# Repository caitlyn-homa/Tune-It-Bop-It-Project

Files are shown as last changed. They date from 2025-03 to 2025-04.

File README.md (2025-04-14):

# Tune-It-Bop-It-Project

## ATMega328p I/O List
| Description | Pin | Label |
| --- | --- | --- |
| Tuner | A0 | TNR |
| Volume | A3 | VOL |
| OLED/Accelerometer  | A4 |  SDA  |
| | A5  |  SCL |
| Speaker (SPK) | 0 | RX |
| | 1 | TX |
| Pull | 2 | PUL | 
| Reset | 3 | RST |
| Motor Reset | 4 | MLS |
| Stepper (MTR) | 5 | st_a |
|  | 6 | st_b |
|  | 7 | st_c |
|  | 8 | st_d |
| Reset LED | 9 | RLD |

## File Directory

### Final_Code
This folder contains the final code uploaded to the microcontroller.
This consists of the main game code as well as the modified class for the mp3 player.

### 3D Print Files
This folder contains every file used for 3D printing, this includes the enclosure as well as the internal mechanical mechanisms.

### prorotype_functions
This contains functions that were created later in the software development and were written in a separate file before integration.

### test_scripts
These scripts were used in the interfacing stage of development and were referenced throughout the process of creating the final code.

### PCB_Files
These files in the design and manufacturing of the PCB, this includes the schematic, the pcb design file, and the exported manufacturing files.

### laser_cut
These files were used to laser cut the score dial and the mesh on the front of the device.

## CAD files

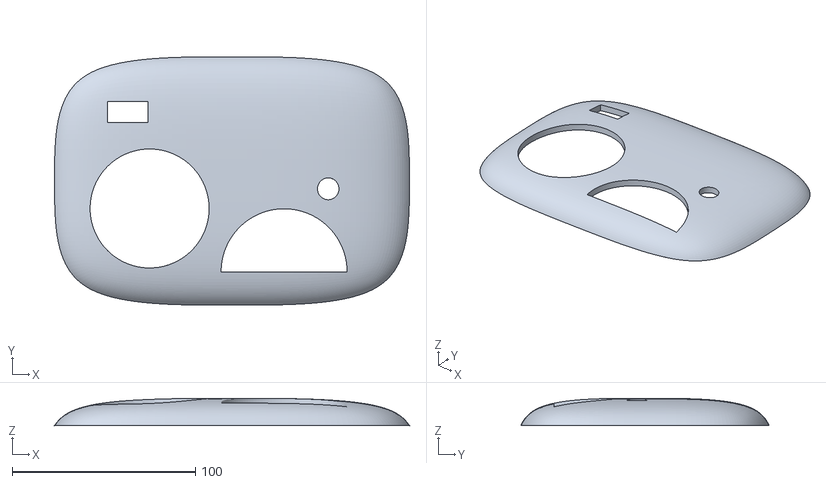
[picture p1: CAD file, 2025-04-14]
3D Print Files/bubbly bop it lid.stl
193.9 x 135.7 x 15.0

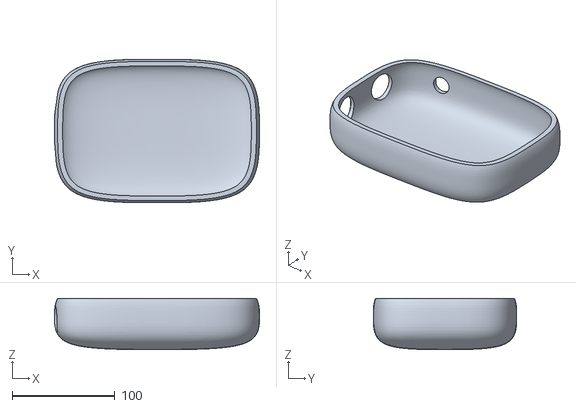
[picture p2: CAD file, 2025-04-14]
3D Print Files/bubbly bop it bottom.stl
200.0 x 140.0 x 50.0

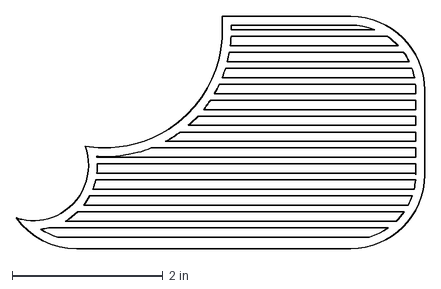
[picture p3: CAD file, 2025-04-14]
laser_cut/grid v2 v1.dxf
5.42 x 3.09 in

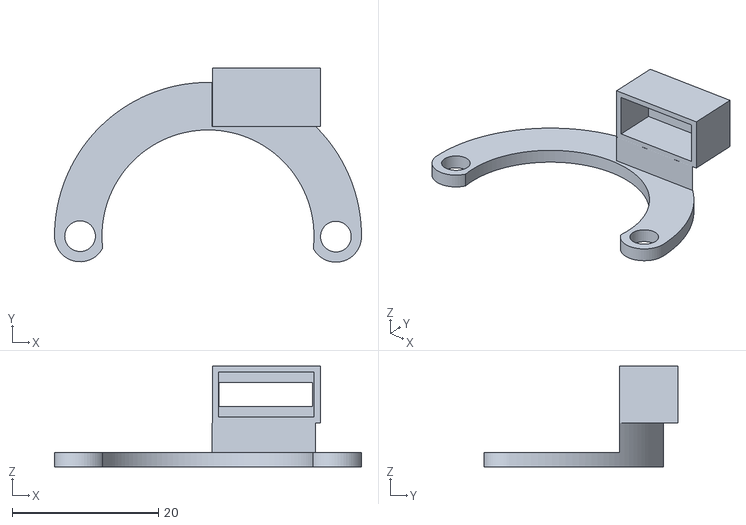
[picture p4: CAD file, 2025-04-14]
3D Print Files/LimitSwitch v1.stl
42.0 x 26.6 x 13.8

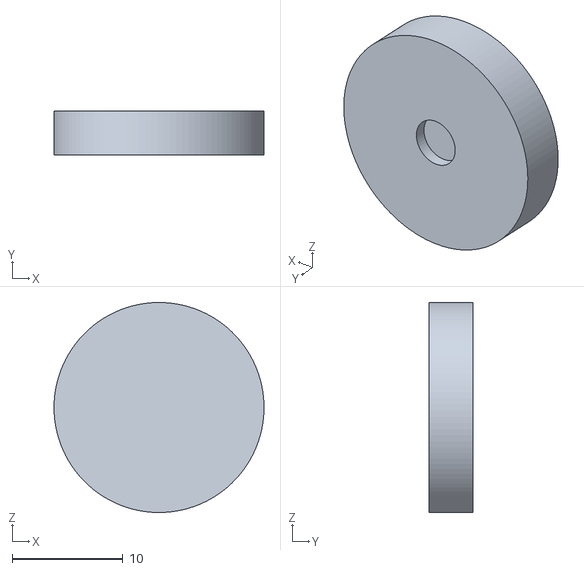
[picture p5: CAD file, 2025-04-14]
3D Print Files/antenna_base.stl
18.9 x 4.00 x 18.9

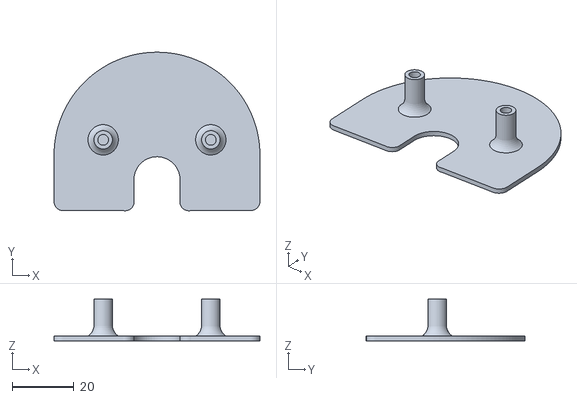
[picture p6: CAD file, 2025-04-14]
3D Print Files/ScorePlate v4.stl
67.0 x 51.6 x 13.5

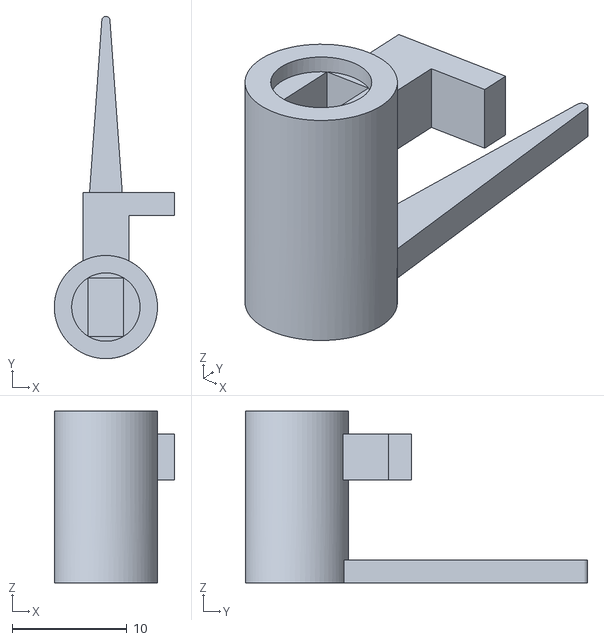
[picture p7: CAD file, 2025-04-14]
3D Print Files/Needle v1.stl
10.5 x 29.9 x 15.0

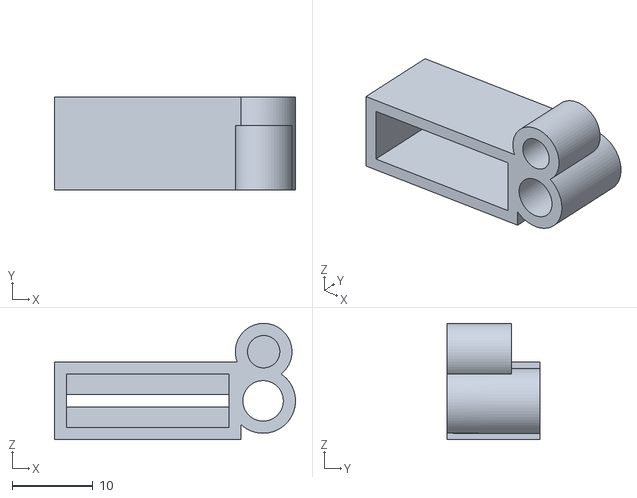
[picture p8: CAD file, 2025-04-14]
3D Print Files/antenna_switch.stl
29.8 x 11.5 x 14.4

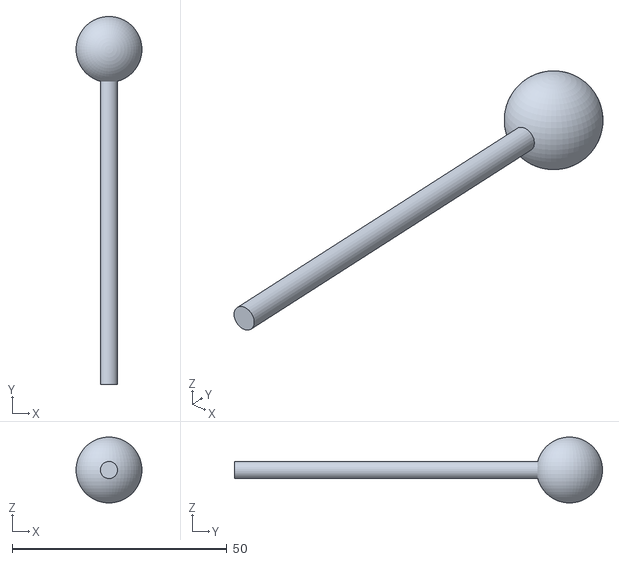
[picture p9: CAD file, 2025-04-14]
3D Print Files/antenna_rod.stl
15.3 x 85.7 x 15.3

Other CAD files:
laser_cut/score dial important v2.dxf

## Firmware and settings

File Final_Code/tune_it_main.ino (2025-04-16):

#include <DFMiniMp3.h>
#include <Adafruit_SSD1306.h>
#include <Adafruit_GFX.h>
#include <SPI.h>
#include <Wire.h>
#include "SparkFunLIS3DH.h" 
#include "Mp3Manager.hpp"

//OLED Variables & Object
#define SCREEN_WIDTH 128
#define SCREEN_HEIGHT 64
#define OLED_ADDR 0x3C
Adafruit_SSD1306 display(SCREEN_WIDTH, SCREEN_HEIGHT, &Wire, -1);

//Accelerometer Object
LIS3DH SensorOne(I2C_MODE, 0x19);
//SD Card Object
Mp3Manager mp3;

//In-Game Variables 
byte score = 0;
byte iteration = 0;
bool isComplete = false;
volatile bool restartPressed = false;
int numRounds = 99;
float time_to_complete = 4.0;
//Used to calculate time interval decrease - following exponential decay
float time_constant = -numRounds/log(0.7/4); 

int volume = analogRead(A3)/20.5;

//Used to debug when having memory issues 
extern int __heap_start, *__brkval;
int freeMemory() {
  int v;
  return (int)&v - (__brkval == 0 ? (int)&__heap_start : (int)__brkval);
}

void setup() {
  pinMode(3, INPUT_PULLUP);   // Start button
  attachInterrupt(digitalPinToInterrupt(3), restart_game, FALLING);
  pinMode(4, INPUT_PULLUP);   // Motor Reset
  pinMode(2, INPUT_PULLUP);   // Pull sensor
  pinMode(A0, INPUT);         // Potentiometer

  // Stepper motor pins
  for (int i = 5; i <= 8; i++) pinMode(i, OUTPUT);

  //Oled Set-up
  display.begin(SSD1306_SWITCHCAPVCC, OLED_ADDR);
  display.clearDisplay();
  display.display();

  //Accelerometer Set-up
  SensorOne.begin();
}

//Main Game Loop
void loop() {
  waitMilliseconds(100);
  oled_display_str(F("Press"), 2, 0, true);
  oled_display_str(F("Start"), 2, 1, false);

  //If game is about to start - will jump to ISR first 
  if (restartPressed) {
    restartPressed = false;   //Reset flag if start has been pushed 
    mp3.begin();              //Begin song 
    waitMilliseconds(10);
    motor_reset();            //Put score dial back 
    oled_display_str(F("Get Ready!"), 2, 0, true);  //Warn player the game will start soon
    oled_countdown(3);

    //Start executing the 99 rounds of the game 
    for (iteration = 0; iteration < numRounds; iteration++) {
      mp3.loop();       //Keeps song playing 
      isComplete = false;
      byte action_number = random(1, 4);

      if (action_number == 1) {                        //PULL-IT == 1
        oled_display_str(F("Pull It!"), 2, 0, true);
        waitMilliseconds(300);
        isComplete = has_pulled(time_to_complete);
      } else if (action_number == 2) {                 //TUNE-IT == 2
        oled_display_str(F("Tune It!"), 2, 0, true);
        waitMilliseconds(300);
        isComplete = has_tuned(time_to_complete);
      } else {
        oled_display_str(F("Shake It!"), 2, 0, true);  //SHAKE-IT == 3
        waitMilliseconds(300);
        isComplete = has_shaken(time_to_complete);
      }

      //If player was successful 
      if (isComplete) {
        score++;                //Increase score
        mp3.setVolume(volume);  //Restore the audio 
        oled_display_str(F("Signal"), 2, 0, true);    
        oled_display_str(F("Connected!"), 2, 1, false);
        rotate_motor(1, 2);    //Move score dial 
        waitMilliseconds(600);
      } else { //The player was unsuccessful 
        player_lost(score);
        break; //Exit the game - do not start next round 
      }

      //Update game time according to the exponetial decay - using iteration as "time" passed
      time_to_complete = 4 * exp(-(iteration+1)/time_constant);
    }
    
    //Player wins if they score 99 points 
    if (score == numRounds) player_won();
    iteration = 0; //Reset game iteration 
  }
}

//ISR when start has been pushed 
void restart_game() {
  //Debounce 
  static unsigned long lastInterruptTime = 0;
  unsigned long currentTime = millis();
  if (currentTime - lastInterruptTime > 300) {
    lastInterruptTime = currentTime;  
    score = 0;              //Reset game variables 
    time_to_complete = 4;
    iteration = 0;
    restartPressed = true;  //Set flag to true to begin game 
  }
}

//Routine when action is PULL-IT
bool has_pulled(float time_lim) {
  //Set-up countdown for time player has to pull the antenna
  int duration = (int)(time_lim * 1000);
  int startState = digitalRead(2);
  int threshold = 600; //Tune-It threshold 
  int startVal = analogRead(A0);  //Reads antenna input 

  mp3.setVolume(volume*0.7);  //Cut-out the audio 

  //Begin countdown 
  unsigned long start = millis();
  while ((millis() - start) <= duration) {
    //Check input for if the antenna has been pulled 
    if (digitalRead(2) != startState) {
      mp3.setVolume(volume);
      return true;  //Return success
    } 

    //Check if player has turned the Tune-It instead 
    if (abs(analogRead(A0) - startVal) > threshold) {
      mp3.setVolume(volume);
      return false; //Return fail 
    }
    mp3.loop(); //Keeps audio playing
  }
  mp3.setVolume(volume);
  return false; //Timer ran out - player lost 
}

//Routine when action is TUNE-IT
bool has_tuned(float time_lim) {
  //Set-up countdown for time player has to turn the tuning knob 
  int duration = (int)(time_lim * 1000);
  int threshold = 300;             //Tune-it threshold 
  int startVal = analogRead(A0);   //Tune-its initial input value 
  int startState = digitalRead(2); //Pull-its initial input state 
  int cuts = 0;                    //Audio effects for Tune-it
  int cuttime = 20;

  //Begin countdown and checking inputs 
  unsigned long start = millis();
  while ((millis() - start) <= duration) {
    //Check if player has turned the tuning knob above threshold 
    if (abs(analogRead(A0) - startVal) > threshold) {
      mp3.setVolume(volume);
      return true; //Return success
    }

    //Cut out the audio 
    if(millis()-start > cuts*cuttime){
      mp3.setVolume(volume*(random(3,10)/10.0));
      ++cuts;
    }

    //Check if player has pulled the antenna 
    if (digitalRead(2) != startState) {
      mp3.setVolume(volume);
      return false;  //Return fail 
    } 

    mp3.loop(); //Keeps audio playing 
  }
  mp3.setVolume(volume);
  return false; //Time ran out and player lost 
}

//Routine when action is SHAKE-IT
bool has_shaken(float time_lim) {
  //Set-up countdown and other variables to test if radio has been shaken 
  int duration = (int)(time_lim * 1000);
  float threshold = 1.25;     //Shake-it threshold 
  int cuttime = 200;          //Audio distortion - 200ms between cuts
  int cuts = 0; 
  int tune_threshold = 600;   //Tune-it threshold 
  int startVal = analogRead(A0);  //Tune-its starting input value
  int startState = digitalRead(2);  //Pull-its starting input state 

  //Begin countdown and checking inputs 
  unsigned long start = millis();
  while ((millis() - start) <= duration) {
    //Reading x,y, and z direction accelerations and finding its magnitude 
    float ax = SensorOne.readFloatAccelX();   
    float ay = SensorOne.readFloatAccelY();
    float az = SensorOne.readFloatAccelZ();
    float mag = sqrt(ax * ax + ay * ay + az * az);

    if(millis()-start > cuttime*cuts) {
      mp3.setVolume(volume*round(random(0,2))); //Decrease radio's volume 
      ++cuts;
    }

    //Check if radio was shaken above the threshold
    if (mag > threshold) {
      mp3.setVolume(volume);
      return true; //Return success
    }

    //Check if the antenna has been pulled 
    if (digitalRead(2) != startState) {
      mp3.setVolume(volume);
      return false; //Return fail 
    }  

    //Check is tuning knob has been turned 
    if (abs(analogRead(A0) - startVal) > tune_threshold) {
      mp3.setVolume(volume);
      return false; //Return fail 
    }

    mp3.loop(); //Keeps audio playing 
  }
  return false; //Timer ran out - player loses 
}

//Routine when player loses - input argument = their final score 
void player_lost(byte final_score) {
  oled_display_str(F("You Lost"), 2, 0, true);
  waitMilliseconds(1500);
  oled_display_str(F("Score:"), 2, 0, true);
  waitMilliseconds(500);
  oled_display_score(final_score);
  waitMilliseconds(2000);
  iteration = 101;  //Set iteration above 99 to exit game loop 
}

//Routine when player wins 
void player_won() {
  oled_display_str(F("Congrats!"), 2, 0, true);
  waitMilliseconds(2000);
  oled_display_str(F("You Win!"), 2, 0, true);
  waitMilliseconds(2000);
}

/*Function to display a string to OLED 
  Input arguments - string (storing in flash), size = text size, y = row to put string on, 
  isClear = should oled clear whole display first */
void oled_display_str(const __FlashStringHelper *disp, byte size, byte y, bool isClear) {
  if (isClear){ 
    display.clearDisplay();
  }
  display.setTextSize(size);      //Font size 
  display.setTextColor(WHITE);    
  display.setCursor(0, size*y*12);  //Put cursor to appropriate row 
  display.println(disp);            //Print the string to the oled 
  display.display();      
} 

//Function to display score to OLED - input argument = score 
void oled_display_score(byte score) {
  display.clearDisplay();         //Clear display 
  display.setTextSize(4);         //Font size
  display.setTextColor(WHITE);
  display.setCursor(0, 10);       //Set cursor to top row 
  display.println(score);         //Print the score to the oled 
  display.display();
}

//Function to display a countdown on the OLED - input argument = how many seconds is the timer
void oled_countdown(int seconds) {
  for (int i = seconds; i > 0; i--) { 
    oled_display_score(i);
    waitMilliseconds(1000); //Wait one second before continuing 
  }
}

//Function to delay microcontroller without stopping all other processes - input = delay time in ms 
void waitMilliseconds(uint16_t ms) {
  uint32_t start = millis();
  while ((millis() - start) < ms) {
    mp3.loop();
    //Check if volume has been changed here 
    if(abs(analogRead(A3)/20.5-volume)>5) {
      volume = analogRead(A3)/20.5;
      mp3.setVolume(volume);
    }
    delay(1);
  }
}

//Function to rotate motor 
void rotate_motor(int t_step, int steps) {
  //Pins where motor is connected to 
  int st_a = 5;
  int st_b = 6;
  int st_c = 7;
  int st_d = 8;
  
  //Drive the stepper motor using appropriate pins for each step 
  for(int i = 0; i < steps; ++i) {
    digitalWrite(st_a, LOW); //A
    digitalWrite(st_b, HIGH);
    digitalWrite(st_c, HIGH);
    digitalWrite(st_d, HIGH);
    delay(t_step);
    digitalWrite(st_a, LOW); //AB
    digitalWrite(st_b, LOW);
    digitalWrite(st_c, HIGH);
    digitalWrite(st_d, HIGH);
    delay(t_step);
    digitalWrite(st_a, HIGH); //B
    digitalWrite(st_b, LOW);
    digitalWrite(st_c, HIGH);
    digitalWrite(st_d, HIGH);
    delay(t_step);
    digitalWrite(st_a, HIGH); //BC
    digitalWrite(st_b, LOW);
    digitalWrite(st_c, LOW);
    digitalWrite(st_d, HIGH);
    delay(t_step);
    digitalWrite(st_a, HIGH); //C
    digitalWrite(st_b, HIGH);
    digitalWrite(st_c, LOW);
    digitalWrite(st_d, HIGH);
    delay(t_step);
    digitalWrite(st_a, HIGH); //CD
    digitalWrite(st_b, HIGH);
    digitalWrite(st_c, LOW);
    digitalWrite(st_d, LOW);
    delay(t_step);
    digitalWrite(st_a, HIGH); //D
    digitalWrite(st_b, HIGH);
    digitalWrite(st_c, HIGH);
    digitalWrite(st_d, LOW);
    delay(t_step);
    digitalWrite(st_a, LOW); //AD
    digitalWrite(st_b, HIGH);
    digitalWrite(st_c, HIGH);
    digitalWrite(st_d, LOW);
    delay(t_step);
  }
}

//Function to put motor back to it's initial position
void motor_reset() {
  //Pins where motor is connected to 
   int st_a = 5;
   int st_b = 6;
   int st_c = 7;
   int st_d = 8;
   int t_step = 2; //Step size 

   //Checking limit switch if motor is back in starting spot
   while(digitalRead(4)==0) {
     digitalWrite(st_a, LOW); //AD
     digitalWrite(st_b, HIGH);
     digitalWrite(st_c, HIGH);
     digitalWrite(st_d, LOW);
     delay(t_step);
     digitalWrite(st_a, HIGH); //D
     digitalWrite(st_b, HIGH);
     digitalWrite(st_c, HIGH);
     digitalWrite(st_d, LOW);
     delay(t_step);
     digitalWrite(st_a, HIGH); //CD
     digitalWrite(st_b, HIGH);
     digitalWrite(st_c, LOW);
     digitalWrite(st_d, LOW);
     delay(t_step);
     digitalWrite(st_a, HIGH); //C
     digitalWrite(st_b, HIGH);
     digitalWrite(st_c, LOW);
     digitalWrite(st_d, HIGH);
     delay(t_step);
     digitalWrite(st_a, HIGH); //BC
     digitalWrite(st_b, LOW);
     digitalWrite(st_c, LOW);
     digitalWrite(st_d, HIGH);
     delay(t_step);
     digitalWrite(st_a, HIGH); //B
     digitalWrite(st_b, LOW);
     digitalWrite(st_c, HIGH);
     digitalWrite(st_d, HIGH);
     delay(t_step);
     digitalWrite(st_a, LOW); //AB
     digitalWrite(st_b, LOW);
     digitalWrite(st_c, HIGH);
     digitalWrite(st_d, HIGH);
     delay(t_step);
     digitalWrite(st_a, LOW); //A
     digitalWrite(st_b, HIGH);
     digitalWrite(st_c, HIGH);
     digitalWrite(st_d, HIGH);
     delay(t_step);
   }
 }

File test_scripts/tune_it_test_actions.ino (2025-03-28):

#include <Adafruit_SSD1306.h>
#include <Adafruit_GFX.h>
#include <SPI.h>
#include <Wire.h>
#include "SparkFunLIS3DH.h" 

//Keep track of player's score throughout the game
byte score = 0;
//Initial time player has to complete a task [seconds]
int time_to_complete = 3;
//Keeps track whether action was successfully completed or not 
bool isComplete = false;
//Keeps track of what round player is on - will be used to exit loop if player loses 
byte iteration = 0;
//Flag for if game is restarting 
bool restartPressed = false;

// Declaration for an SSD1306 display connected to I2C (SDA, SCL pins)
#define SCREEN_WIDTH 128 // OLED display width, in pixels
#define SCREEN_HEIGHT 64 // OLED display height, in pixels
Adafruit_SSD1306 display(SCREEN_WIDTH, SCREEN_HEIGHT, &Wire, -1);
LIS3DH SensorOne( I2C_MODE, 0x19 );

void setup() {
  //Seed random number generation with current time -ensures variation in the sequence of random numbers 
  randomSeed(analogRead(A1));

  //Pin Set-Up 
  // Reset/Start button
  pinMode(8, OUTPUT);
  pinMode(3, INPUT_PULLUP);
  attachInterrupt(digitalPinToInterrupt(3), restart_game, LOW);
  // Pull Task
  pinMode(2, INPUT_PULLUP);
  // Tune Task
  pinMode(A0, INPUT);
  // Shake Task
  pinMode(A5, INPUT);
  // Stepper Motor 
  pinMode(5, OUTPUT); //st_a
  pinMode(6, OUTPUT); //st_b
  pinMode(7, OUTPUT); //st_c
  pinMode(8, OUTPUT); //st_d
  // OLED Display
  pinMode(A4, OUTPUT);  
  // Speaker 
  pinMode(0, INPUT);
  pinMode(1, OUTPUT);

  // Volume 
  pinMode(A3, INPUT);

  //Set these pins up with LEDS & current limiting resistors to indicate which action has been selected 
  // just while the sound is not set up 
  pinMode(11, OUTPUT); // Pull it
  pinMode(12, OUTPUT); // Tune it
  pinMode(13, OUTPUT); // Shake it

  //OLED set-up 
  oled_set_up();

}

void loop() {

  oled_display_str("Press Start", 2);

  //Restart Game
  if(restartPressed)
  {
    score = 0;
    time_to_complete = 10;
    //motor_reset();
  
    restartPressed = false;
  
  
    oled_display_str("Get Ready!", 2);
    countdown(3);

    //Game loop - Player wins after 99 rounds 
    for(iteration = 0; iteration<99; iteration++)
    {
      //Reset action completion variable back to false
      isComplete = false;

      //Generates random number 1 through 3 to select action - MAP -> #1 = Pull-it #2 = Tune-it #3 = Shake-it
      byte action_number = random(1,4);

      //Pull-It! 
      if(action_number == 1)
      {
        //Cut out sound/music
        //Play Pull it! sound
        digitalWrite(11, HIGH);
        oled_display_str("Pull It!", 2);
        delay(1000);
        isComplete = has_pulled(time_to_complete);

        //If action is completed within the time 
        if (isComplete)
        {
          digitalWrite(11, LOW);
          //Indicate success - maybe continue playing music?
          score++; 
          oled_display_score(score);
          rotate_motor(1,2);
          delay(500);
        } 
        else {
          //Cue loss protocol
          player_lost(score);
          delay(1000);
        }
      }
      //Tune-It!
      if(action_number == 2)
      {
        //Have music "flip" between channels 
        //Play Tune it! sound
        digitalWrite(12, HIGH);
        oled_display_str("Tune It!", 2);
        delay(1000);
        isComplete = has_tuned(time_to_complete);

        //If action is completed within the time 
        if (isComplete)
        {
          digitalWrite(12, LOW);
          //Indicate success - maybe continue playing music?
          score++; 
          oled_display_score(score);
          rotate_motor(1,2);
          delay(500);
        } 
        else {
          //Cue loss protocol
          player_lost(score);
        }
      }
      //Shake-It!
      if(action_number == 3)
      {
        //Have static sound play 
        //Play Shake it! sound
        digitalWrite(13, HIGH);
        oled_display_str("Shake It!", 2);
        delay(1000);
        isComplete = has_shaken(time_to_complete);

        //If action is completed within the time 
        if (isComplete)
        {
          digitalWrite(13, LOW);
          //Indicate success - maybe continue playing music?
          score++; 
          oled_display_score(score);
          rotate_motor(1,2);
          delay(500);
        } 
        else {
          //Cue loss protocol
          player_lost(score);
        }
        
      }
      //End of actions 

      //Decrease time to complete action every 5th iteration or so - for 99 iterations - will decrease 19 times
      if(iteration % 5 == 0)
      {
        //Will decrease by 2.85 seconds if player makes it to the end 
        time_to_complete = time_to_complete - 0.15;
      }

    } //end of for loop

    //Player has won - indicate the win somehow
    if(score == 99)
    {
      player_won();
    }

    //Reset game back to starting conditions
  }
  iteration = 0;
}

void countdown(int time) 
{
  time = time * 1000;  // Convert time to milliseconds
  int starttime = millis();
  int endtime = starttime;
  int lastUpdateTime = starttime;  // To track when to update the display

  while ((endtime - starttime) < time) {  // Run until the time limit is reached
    endtime = millis();  // Update the current time

    if (endtime - lastUpdateTime >= 1000) {  // If 1 second has passed
      lastUpdateTime = endtime;  // Update the last update time
      int secondsPassed = (endtime - starttime) / 1000;  // Calculate the seconds passed
      oled_display_score(secondsPassed);  // Update the display
    }
  }
}

//Steps to follow if player has lost 
void player_lost(byte score)
{
  oled_display_str("You Lost", 3);
  delay(2000);
  //Play broken radio sounds 
  //Display final score 

  //Set iteration to 101 to exit game loop
  iteration = 101;
  
}
//Steps to follow if player has won
void player_won()
{
  //
}

//Sets restart flag to true 
void restart_game()
{
  if(iteration > 0)
  {
    iteration = 101;
    restartPressed = false;
  }
  else
  {
  restartPressed = true;
  }
  

}
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

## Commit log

2025-03-21 Adding Reset Interrupt File
2025-03-25 Add test for random number generation
    This test needs three LEDS and their current limiting resistors set up at digital pins 6, 7, and 8 - microprocessor will generate a number and light up corresponding pin
2025-03-25 Add test for countdown interval
    This test shows the countdown interval using a method that should allow the microprocessor to do other tasks while countdown is occurring. Put a LED with current limiting resistor at digital pin 8 - 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
2025-03-26 Added action testing
    Put LEDS at digital pins 11,12,13 - will light up when action is called - and it will turn off once action is complete - actions should be set up right? - code may need to be checked again
2025-03-28 Update tune_it_test_actions.ino
    updated motor functions
2025-03-28 Update interrupt
2025-03-28 update interrupt added countdown into game
2025-03-28 Update tune_it_test_actions.ino
    Working game with reset
    [tune_it_test_actions.ino]
2025-04-09 Update tune_it_main.ino
    Fixed volume control
    [tune_it_main.ino]
2025-04-14 Create motor
2025-04-14 Rename multi line string function to prototype_functions/multi line string function
2025-04-14 Rename press start display to prototype_functions/press start display
2025-04-14 Update and rename Status Report.Txt to PCB_Files/manufacturing/Status Report.Txt
2025-04-14 Update and rename TuneIt-RectHoles.TXT to PCB_Files/manufacturing/TuneIt-RectHoles.TXT
2025-04-14 Update and rename TuneIt-macro.APR_LIB to PCB_Files/manufacturing/TuneIt-macro.APR_LIB
2025-04-14 Update and rename TuneIt.DRR to PCB_Files/manufacturing/TuneIt.DRR
2025-04-14 Update and rename TuneIt.EXTREP to PCB_Files/manufacturing/TuneIt.EXTREP
2025-04-14 Update and rename TuneIt.GBL to PCB_Files/manufacturing/TuneIt.GBL
    [TuneIt.GBL]
2025-04-14 Update and rename TuneIt.GBO to PCB_Files/manufacturing/TuneIt.GBO
    [TuneIt.GBO]
2025-04-14 Update and rename TuneIt.GBP to PCB_Files/manufacturing/TuneIt.GBP
    [TuneIt.GBP]
2025-04-14 Update and rename TuneIt.GBS to PCB_Files/manufacturing/TuneIt.GBS
    [TuneIt.GBS]
2025-04-14 Update and rename TuneIt.GKO to PCB_Files/manufacturing/TuneIt.GKO
    [TuneIt.GKO]
2025-04-14 Update and rename TuneIt.GM to PCB_Files/manufacturing/TuneIt.GM
2025-04-14 Update and rename TuneIt.GTL to PCB_Files/manufacturing/TuneIt.GTL
    [TuneIt.GTL]
2025-04-14 Update and rename TuneIt.GTO to PCB_Files/manufacturing/TuneIt.GTO
    [TuneIt.GTO]
2025-04-14 Update and rename TuneIt.GTP to PCB_Files/manufacturing/TuneIt.GTP
    [TuneIt.GTP]
2025-04-14 Update and rename TuneIt.GTS to PCB_Files/manufacturing/TuneIt.GTS
    [TuneIt.GTS]
2025-04-14 Update and rename TuneIt.LDP to PCB_Files/manufacturing/TuneIt.LDP
2025-04-14 Update and rename TuneIt.REP to PCB_Files/manufacturing/TuneIt.REP
2025-04-14 Update and rename TuneIt.RUL to PCB_Files/manufacturing/TuneIt.RUL
2025-04-14 Update and rename TuneIt.TXT to PCB_Files/manufacturing/TuneIt.TXT
2025-04-14 Update and rename TuneIt.apr to PCB_Files/manufacturing/TuneIt.apr
2025-04-14 Update and rename grid v2 v1.dxf to laser_cut/grid v2 v1.dxf
    [grid v2 v1.dxf]
2025-04-14 Rename score dial important v2.dxf to laser_cut/score dial important v2.dxf
    [score dial important v2.dxf]
